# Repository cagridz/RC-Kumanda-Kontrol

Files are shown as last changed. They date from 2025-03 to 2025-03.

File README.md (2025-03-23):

FLYSKY FS-İ6X 2A uzaktan kumanda ile Arduino Mega kontrollü 2WD Robot kontrolü için yazılmıştır. 
Daha sonra eklenecek olan Lidar, Lora, Ultrasonik sensör, GPS modülü de koda eklenmiştir. Aşağıda FS-İA6B alıcısının bağlantı şeması yer almaktadır. 

Devre 3S 18650 Lityum batarya ile beslenmektedir. Pil kontrolü için BMS kullanılmıştır. Bataryaya 2 adet DC-DC voltaj düşürücü bağlıdır. Biri doğrudan motoru beslemektedir. Motor için 6V 250 Rpm tip kullanılmış olup, motor sürücü için L298N çift motor sürücü kullanılmıştır ve ayrı beslenmektedir. Motor gerilimine bağlı olarak besleme gerilimi 6V ile sınırlandırılmıştır. Diğer DC-DC voltaj düşürücü ise Arduino Mega ve Alıcıyı beslemektedir. 

Adsız


Robotun önüne ve arkasına yerleştirilen HC - SR04 sensörü, hareket edilen taraftaki engeli algılayıp durması gerektiği için buna göre ayrı ayrı değerlendirilmiştir. Kumanda edildiği yönde engel algıladığı zaman durmaktadır. 

WhatsApp Image 2025-03-24 at 00 35 06

Mesafe sensörleri 20 cm de durmaktadır.

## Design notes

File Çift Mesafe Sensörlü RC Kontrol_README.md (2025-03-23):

FLYSKY FS-İ6X 2A uzaktan kumanda ile Arduino Mega kontrollü 2WD Robot kontrolü için yazılmıştır. 
Daha sonra eklenecek olan Lidar, Lora, Ultrasonik sensör, GPS modülü de koda eklenmiştir. Aşağıda FS-İA6B alıcısının bağlantı şeması yer almaktadır. 

Devre 3S 18650 Lityum batarya ile beslenmektedir. Pil kontrolü için BMS kullanılmıştır. Bataryaya 2 adet DC-DC voltaj düşürücü bağlıdır. Biri doğrudan motoru beslemektedir. Motor için 6V 250 Rpm tip kullanılmış olup, motor sürücü için L298N çift motor sürücü kullanılmıştır ve ayrı beslenmektedir. Motor gerilimine bağlı olarak besleme gerilimi 6V ile sınırlandırılmıştır. Diğer DC-DC voltaj düşürücü ise Arduino Mega ve Alıcıyı beslemektedir. 

Adsız


Robotun önüne ve arkasına yerleştirilen HC - SR04 sensörü, hareket edilen taraftaki engeli algılayıp durması gerektiği için buna göre ayrı ayrı değerlendirilmiştir. Kumanda edildiği yönde engel algıladığı zaman durmaktadır. 

WhatsApp Image 2025-03-24 at 00 35 06

Mesafe sensörleri 20 cm de durmaktadır. 
Ayarlanabilir DC-DC Voltaj Düşürücü olarak 1 Adet LM2596 ve 1 Adet XL4015 kullanılmıştır. Batarya olarak lityum 3S 18650 batarya, 3S 40A BMS kullanılmıştır. 
L298N Motor sürücü XL4015 ile beslenmiş, 2 Adet HC SR04, Arduino Mega, FS-IA6B 6 kanallı RC Kumanda alıcısı ise diğer voltaj düşürücü olan LM2596 ile beslenmiştir. LM2596 ya bağlı olan modüllerin tamamında ortak GND bağlantısı yapılmıştır. 

2 tekerlekli, 1 sarhoş tekerlekli robot şasesi için 2WD Chassis tasarımı kullanılmıştır. 2 adet 3D baskı plaka, 4 adet 3D baskı kolon ile ve 4 mm sunta civatası ile birleştirilmiştir. 

Aynı zamanda ani fren amacı ile sol+geri tuşu ile frenleme tuş kombinasyonu yer almaktadır.

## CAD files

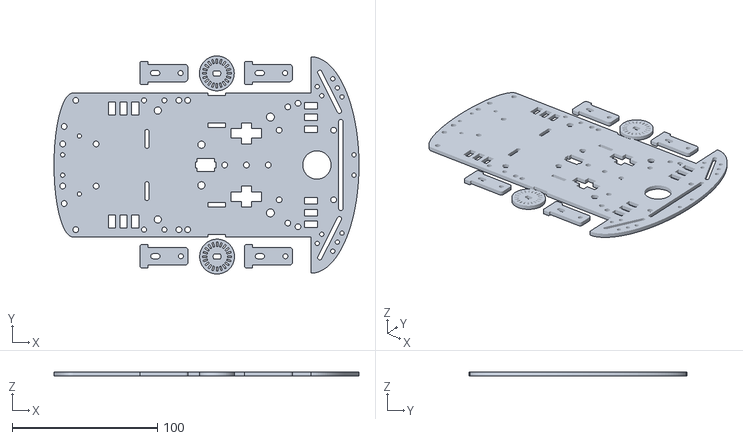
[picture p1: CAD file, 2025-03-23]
3D Parçalar/RobotChassis.STL
210.0 x 150.1 x 3.00

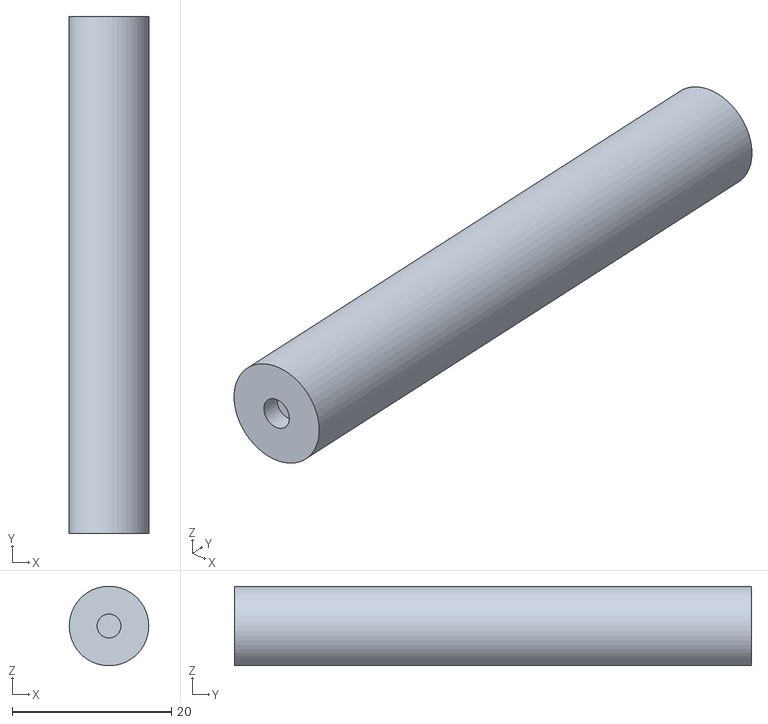
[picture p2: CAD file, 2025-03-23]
3D Parçalar/Vertical Holder.stl
10.0 x 65.0 x 9.98

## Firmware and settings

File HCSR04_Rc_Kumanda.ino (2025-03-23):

#include <L298N.h>
#include "Wire.h"
#include <Adafruit_Sensor.h>
#include <Adafruit_HMC5883_U.h>
#include <Servo.h>
#include <TinyGPS++.h>
#include <SoftwareSerial.h>
#include "LoRa_E32.h"
#include <IBusBM.h>

#define LORA_RX 10
#define LORA_TX 11
#define LORA_M0 2
#define LORA_M1 3
#define LORA_AUX 5

#define GPS_RX 12
#define GPS_TX 13
#define GPS_BAUD 9600

#define TRIG_PIN 22
#define ECHO_PIN 23
#define TRIG_PIN_2 24
#define ECHO_PIN_2 25
#define OBSTACLE_THRESHOLD 20

#define IBUS_RX_PIN 19

IBusBM ibus;
L298N motor1(9, 8, 7);
L298N motor2(6, 5, 4);

SoftwareSerial LoRaSerial(LORA_RX, LORA_TX);
SoftwareSerial portgps(GPS_RX, GPS_TX);
LoRa_E32 e32ttl(&LoRaSerial);
TinyGPSPlus gps;
Adafruit_HMC5883_Unified compass = Adafruit_HMC5883_Unified(12345);

int desired_heading;
int compass_heading;
int compass_dev = 5;
bool goToTarget = false;
bool returning = false;
double targetLat = 0.0;
double targetLon = 0.0;
unsigned long startTime = 0;
const unsigned long waitTime = 30000;

typedef struct {
  byte pitch;
  byte roll;
  byte yaw;
} Signal;

Signal data;

int throttle = 0;
int steering = 0;
int manualControlSwitch = 0;  // CH6: SWD - kumanda erişim tuşu
unsigned long lastControlTime = 0;
unsigned long lastPrintTime = 0;
unsigned long lastLoRaTime = 0;

void setup() {
  Serial.begin(115200);
  Serial1.begin(115200);
  ibus.begin(Serial1);
  portgps.begin(GPS_BAUD);
  LoRaSerial.begin(9600);
  e32ttl.begin();
  Wire.begin();

  pinMode(TRIG_PIN, OUTPUT);
  pinMode(ECHO_PIN, INPUT);
  pinMode(TRIG_PIN_2, OUTPUT);
  pinMode(ECHO_PIN_2, INPUT);

  pinMode(LORA_M0, OUTPUT);
  pinMode(LORA_M1, OUTPUT);
  pinMode(LORA_AUX, INPUT);
  digitalWrite(LORA_M0, LOW);
  digitalWrite(LORA_M1, LOW);
  Serial.println("Sistem başlatıldı!");
}

void loop() {
  unsigned long currentMillis = millis();
  readFlySkyReceiver();

  if (manualControlSwitch > 1500) {
    controlMotors();
  } else {
    motor1.stop();
    motor2.stop();
  }

  if (currentMillis - lastLoRaTime >= 500) {
    sendLoRaData();
    lastLoRaTime = currentMillis;
  }

  if (currentMillis - lastPrintTime >= 500) {
    Serial.print("Throttle: "); Serial.print(throttle);
    Serial.print(", Steering: "); Serial.print(steering);
    Serial.print(", Kumanda Erişim: "); Serial.println(manualControlSwitch > 1500 ? "AKTİF" : "KAPALI");
    lastPrintTime = currentMillis;
  }
}

void readFlySkyReceiver() {
  ibus.loop();
  throttle = map(ibus.readChannel(2), 1000, 2000, -500, 500);
  steering = map(ibus.readChannel(0), 1000, 2000, 500, -500);
  manualControlSwitch = ibus.readChannel(5);   // CH6 (SWD) - kumanda erişimi
}

void controlMotors() {
  int distance1 = measureDistance(TRIG_PIN, ECHO_PIN);
  delay(50);
  int distance2 = measureDistance(TRIG_PIN_2, ECHO_PIN_2);

  if (distance1 > 0 && distance1 < OBSTACLE_THRESHOLD && throttle > 50) {
    motor1.stop();
    motor2.stop();
    Serial.println("Önde ENGEL ALGILANDI! Duruyorum...");
    return;
  }

  if (distance2 > 0 && distance2 < OBSTACLE_THRESHOLD && throttle < -50) {
    motor1.stop();
    motor2.stop();
    Serial.println("Arkada ENGEL ALGILANDI! Duruyorum...");
    return;
  }

  if (throttle < -450 && steering > 450) {
    motor1.stop();
    motor2.stop();
    Serial.println("FREN MODU AKTİF");
    return;
  }

  int leftMotorSpeed = throttle + steering;
  int rightMotorSpeed = throttle - steering;

  leftMotorSpeed = constrain(leftMotorSpeed, -500, 500);
  rightMotorSpeed = constrain(rightMotorSpeed, -500, 500);

  int leftPower = map(abs(leftMotorSpeed), 0, 500, 0, 255);
  int rightPower = map(abs(rightMotorSpeed), 0, 500, 0, 255);

  if (leftMotorSpeed > 10) {
    motor1.setSpeed(leftPower);
    motor1.forward();
  } else if (leftMotorSpeed < -10) {
    motor1.setSpeed(leftPower);
    motor1.backward();
  } else {
    motor1.stop();
  }

  if (rightMotorSpeed > 10) {
    motor2.setSpeed(rightPower);
    motor2.forward();
  } else if (rightMotorSpeed < -10) {
    motor2.setSpeed(rightPower);
    motor2.backward();
  } else {
    motor2.stop();
  }
}

void sendLoRaData() {
  data.pitch = map(throttle, -500, 500, 0, 255);
  data.roll = 127;
  data.yaw = map(steering, -500, 500, 0, 255);
  e32ttl.sendFixedMessage(21, 179, 7, &data, sizeof(Signal));
}

void requestTargetLocation() {
  Serial.println("Hedef konum isteniyor...");
  ResponseStatus rs = e32ttl.sendFixedMessage(21, 179, 7, "REQUEST_LOCATION", sizeof("REQUEST_LOCATION"));
  Serial.println(rs.getResponseDescription());
}

int measureDistance(int trigPin, int echoPin) {
  digitalWrite(trigPin, LOW);
  delayMicroseconds(2);
  digitalWrite(trigPin, HIGH);
  delayMicroseconds(10);
  digitalWrite(trigPin, LOW);
  long duration = pulseIn(echoPin, HIGH, 30000); // 30 ms timeout
  if (duration == 0) return 999; // zaman aşımı olursa geçersiz mesafe dön
  return duration * 0.034 / 2;
}
